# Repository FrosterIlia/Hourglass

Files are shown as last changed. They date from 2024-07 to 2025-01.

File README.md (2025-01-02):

# Hourglass
Electronic Hourglass

:clapper: Youtube shorts link: https://www.youtube.com/shorts/0R3GjrOCUNI

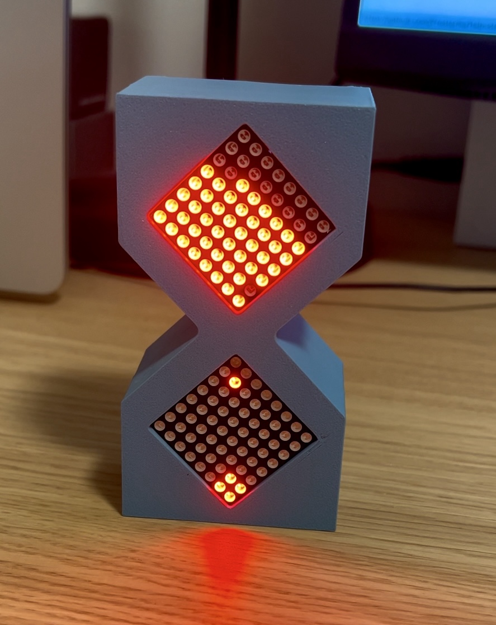
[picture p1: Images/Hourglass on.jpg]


# Algorithm
The main idea behind the algorithm is to check the spots on the matrix in the direction of potential movement. If the spot is empty, the particle moves there.
The circle in which the hourglass can rotate gets divided in 16 segments and every segment has its own order of the neighbouring spots each particle will check as shown in the figure. At 45 degree angle, the second checked spot is chosen randomly to make the simulation look more realistic without overcomplicating the algorithm.

The algorithm doesn't require any floating point numbers or nested loops. All the possible directions are conveniently stored in FLASH and do not take any RAM space. This allows this algorithm to run on basically any microcontroller and show incredible performance even with higher resolution displays.



# Schematic

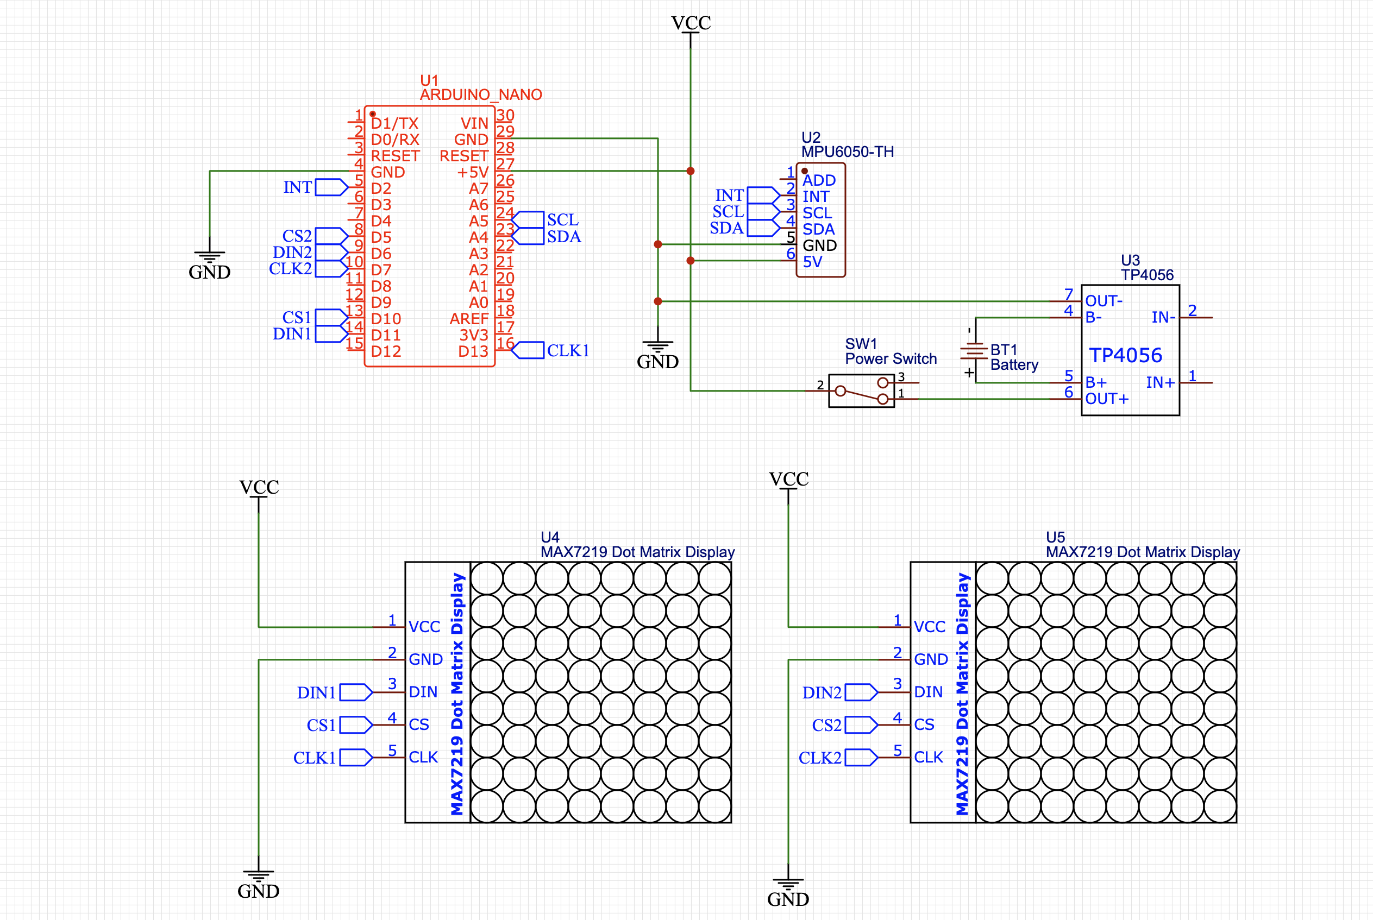
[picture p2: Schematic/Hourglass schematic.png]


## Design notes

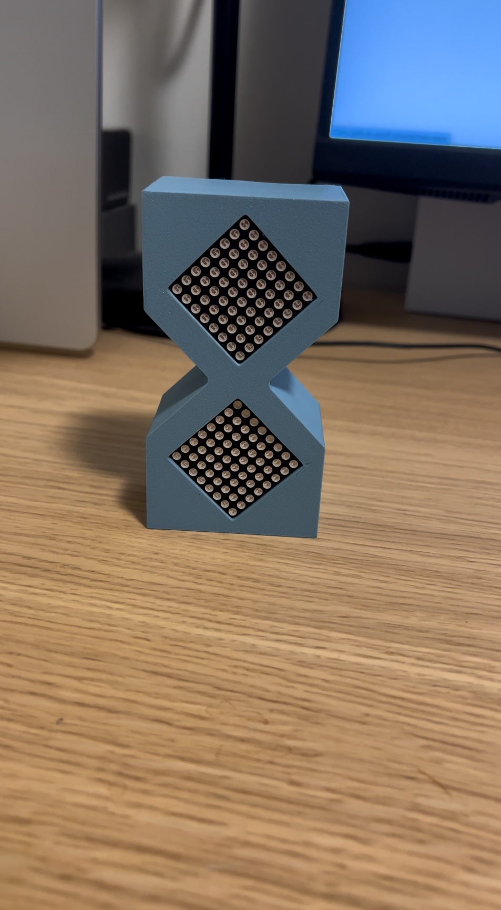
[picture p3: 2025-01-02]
Images/Hourglass off.jpg

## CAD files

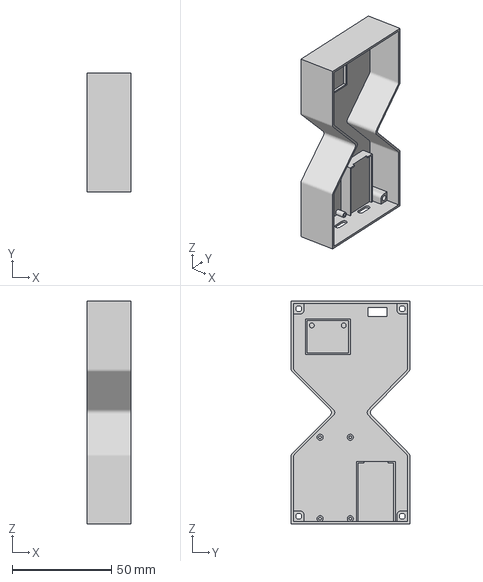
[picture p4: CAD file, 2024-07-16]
3D Models/Hourglass back side v2.3mf
22.0 x 60.0 x 112.4 mm

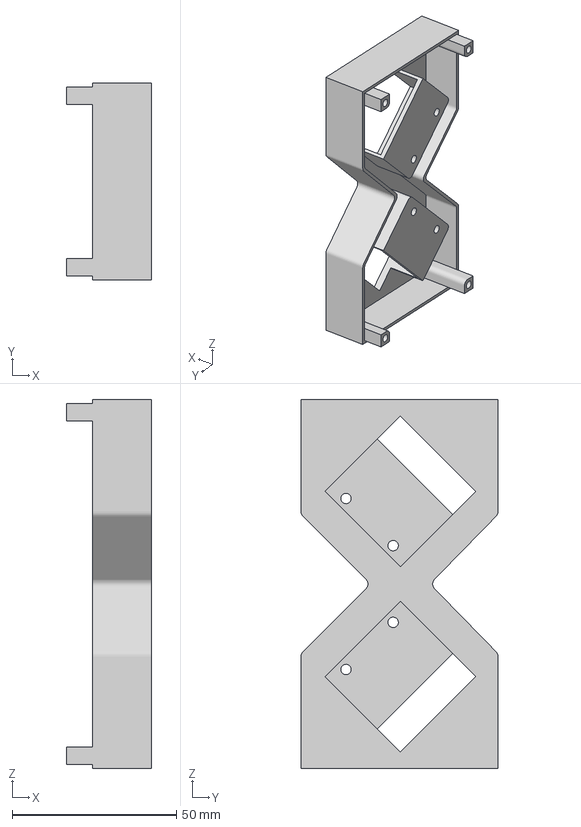
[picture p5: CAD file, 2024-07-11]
3D Models/Hourglass v10 matrix_part.3mf
26.0 x 60.0 x 112.4 mm

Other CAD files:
3D Models/Hourglass v10 back_part.3mf
3D Models/Hourglass v10 back_part.stl
3D Models/Hourglass v10 matrix_part.stl
3D Models/Hourglass v10.f3d

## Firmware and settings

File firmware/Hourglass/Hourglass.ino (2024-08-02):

#include "Gyroscope.h"
#include "Timer.h"

#include <MD_MAX72xx.h>

#define HARDWARE_TYPE MD_MAX72XX::PAROLA_HW
#define MAX_DEVICES 2
#define CS_PIN1 10  // or SS
#define MATRIX_SIZE 8

#define DATA_PIN2 6
#define CLK_PIN2 7
#define CS_PIN2 5

#define MAIN_PERIOD 100
#define CLOCK_PERIOD 1350  // 1 minute

#define OFFSET 14

#define PARTICLES 50


Gyroscope gyro;
MD_MAX72XX matrix1 = MD_MAX72XX(HARDWARE_TYPE, CS_PIN1, MAX_DEVICES);
MD_MAX72XX matrix2 = MD_MAX72XX(HARDWARE_TYPE, DATA_PIN2, CLK_PIN2, CS_PIN2);

uint8_t buffer1[MATRIX_SIZE];
uint8_t new_buffer1[MATRIX_SIZE];

uint8_t buffer2[MATRIX_SIZE];
uint8_t new_buffer2[MATRIX_SIZE];


void setup() {
  randomSeed(analogRead(A0));
  Wire.begin();

  matrix1.begin();
  matrix2.begin();

  gyro.begin();
  clear_matrix(1);
  clear_matrix(2);

  delay(25); // giving gyroscope some time to start giving correct values

  uint8_t top_matrix = get_top_matrix(get_gravity(gyro.get_angle()));
  top_matrix = top_matrix == 0 ? random(1, 3) : top_matrix;

  fill(top_matrix);

  update_matrix(top_matrix);

}

Timer main_timer(MAIN_PERIOD);
Timer clock_timer(CLOCK_PERIOD);

void loop() {

  if (main_timer.isReady()) {
    move_all(1);
    move_all(2);
    update_matrix(1);
    update_matrix(2);
  }

  if (clock_timer.isReady()) {
    uint8_t top_matrix = get_top_matrix(get_gravity(gyro.get_angle()));

    if (top_matrix == 1) {
      if (get_pixel(7, 0, 1) && !get_pixel(0, 0, 2)) {
        set_pixel(7, 0, 0, 1);
        set_pixel(0, 0, 1, 2);
      }
    } else if (top_matrix == 2) {
      if (get_pixel(0, 0, 2) && !get_pixel(7, 0, 1)) {
        set_pixel(7, 0, 1, 1);
        set_pixel(0, 0, 0, 2);
      }
    }
  }
}

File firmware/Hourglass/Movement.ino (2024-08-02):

const int8_t OBSTACLE_X_OFFSET[8] = { 0, -1, -1, -1, 0, 1, 1, 1 };
const int8_t OBSTACLE_Y_OFFSET[8] = { -1, -1, 0, 1, 1, 1, 0, -1 };

const int8_t GRAVITY_CHECK[16][3] = { { 0, -2, -2 },  // 0   // -1 means no check
                                      { 1, 0, 2 },    // 1
                                      { 1, -2, -2 },  // 2 // -2 means random choice
                                      { 1, 2, 0 },    // 3
                                      { 2, -2, -2 },  // 4
                                      { 3, 2, 4 },    // 5
                                      { 3, -2, -2 },  // 6
                                      { 3, 4, 2 },    // 7
                                      { 4, -2, -2 },  // 8
                                      { 5, 4, 6 },    // 9
                                      { 5, -2, -2 },  // 10
                                      { 5, 6, 4 },    // 11
                                      { 6, -2, -2 },  // 12
                                      { 7, 6, 0 },    // 13
                                      { 7, -2, -2 },  // 14
                                      { 7, 0, 6 } };  // 15


void move_all(uint8_t matrix_number) {
  uint8_t gravity = get_gravity(gyro.get_angle());
  if (matrix_number == 2) {
    if (gravity < 4) gravity += 16;
    gravity -= 4;
  }
  for (uint8_t i = 0; i < MATRIX_SIZE; i++) {
    for (uint8_t j = 0; j < MATRIX_SIZE; j++) {
      if (get_pixel(i, j, matrix_number)) {
        move(i, j, get_movement_direction(i, j, gravity, matrix_number), matrix_number);
      }
    }
  }
}


int8_t get_movement_direction(uint8_t x, uint8_t y, uint8_t gravity, uint8_t matrix_number) {
  for (uint8_t i = 0; i < 3; i++) {
    if (GRAVITY_CHECK[gravity][i] == -1) return -1;
    if (GRAVITY_CHECK[gravity][i] == -2) {

      int8_t check_order_value = random(0, 2) ? 1 : -1;

      if (!isObstacle(x, y, (GRAVITY_CHECK[gravity][0] + check_order_value) % 8, matrix_number)) return (GRAVITY_CHECK[gravity][0] + check_order_value) % 8;
      if (!isObstacle(x, y, (GRAVITY_CHECK[gravity][0] - check_order_value) % 8, matrix_number)) return (GRAVITY_CHECK[gravity][0] - check_order_value) % 8;

      break;
    }
    if (!isObstacle(x, y, GRAVITY_CHECK[gravity][i], matrix_number)) return GRAVITY_CHECK[gravity][i];
  }

  return -1;
}

void move(uint8_t x, uint8_t y, int8_t direction, uint8_t matrix_number) {  // direction from 0 to 7

  if (direction < 0) return;
  set_pixel(x, y, 0, matrix_number);
  set_pixel(x + OBSTACLE_X_OFFSET[direction], y + OBSTACLE_Y_OFFSET[direction], 1, matrix_number);
}



bool isObstacle(uint8_t x, uint8_t y, uint8_t direction, uint8_t matrix_number) {  // direction from 0 to 7
  if (get_pixel(x + OBSTACLE_X_OFFSET[direction], y + OBSTACLE_Y_OFFSET[direction], matrix_number) || get_pixel_new(x + OBSTACLE_X_OFFSET[direction], y + OBSTACLE_Y_OFFSET[direction], matrix_number)) {

    return true;  // obstacle detected
  }
  return false;
}

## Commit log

2024-07-11 3D Models added
    [Hourglass v10 back_part.3mf, Hourglass v10 back_part.stl, Hourglass v10 matrix_part.3mf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]
2024-07-16 Schematic added
    [Hourglass back side v2.3mf]
2024-07-31 Gyroscope algorithm rebuilt, matrixes aligned, sand falling added
    Gyroscope does not use dmp for angle calculations anymore. Instead 2 axis accelerations are used.
2024-08-02 Bug with top matrix at the start fixed
    [Hourglass.ino]
2024-08-02 Bug when particles disappeared fixed
    [Movement.ino]
